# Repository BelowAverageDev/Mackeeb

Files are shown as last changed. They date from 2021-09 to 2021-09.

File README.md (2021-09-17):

# Mackeeb
2% macropad mechanical keyboard designed around macintosh keycaps  


## Usage
When you plug it in, the Mackeeb will run its main mode.

### Main mode
| Action | Result |
| --- | --- |
| Press Button 1 | Macro A |
| Press Button 2 | Macro B |
| Hold Button 1 | Macro C |
| Hold Button 2 | Macro D |
| Hold Button 1 & 2 together  | Switch to backlight set mode  |  

### Backlight set mode
| Action | Result |
| --- | --- |
| Press Button 1 | Increase Brightness |
| Press Button 2 | Decrease Brightness |
| Hold Button 1 & 2 together  | Switch to main mode |

### Changing macros
To set Macro A-D, you need to put the device in config mode using the following steps:
1. Unplug the Mackeeb
2. Hold down Button 1 & 2 together
3. Plug in the Mackeeb
4. The underglow will begin flashing slowly. You may release Button 1 & 2
5. A new drive titled `CIRCUITPY` should appear on your computer
6. Open `CIRCUITPY/main.py` in any text editor
7. Modify `BUTTON_A_KEYS`, `BUTTON_B_KEYS`, `BUTTON_C_KEYS`, `BUTTON_D_KEYS` to your liking
8. Save `main.py`
9. Unplug and re-plug the Mackeeb

Note: These macros can be sequences of keystrokes, modifier keys, and combinations. For example, you can do a complex action like: `[[Keycode.COMMAND, Keycode.F], "search", Keycode.ENTER]` to search for a string, and then hit enter!

If your macros do not work as expected, you likely made an error. You can debug your macros by connecting to the trinket over a serial port, where any errors will be printed.

## Building your own

### Materials
- [Trinket m0](https://www.adafruit.com/product/3500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)
- [Macintosh keycaps](https://www.keebmonkey.com/products/keebmonkey-mac-modular-artisan-keycap?_pos=1&_sid=b556e45d8&_ss=r)
- 2x Mechanical keyswitches
- 3d printer (or access to one)
- 1x 3mm LED
- 1x Resistor (I used 200 ohm)
- Wire (recommend silicon coated for flexibility)
- Soldering iron
- Solder
- Flux
- MicroUSB cable

### Circuit
Circuit Diagram

Note that the switch connected on pin 3 will be the switch in the back, and the switch connected on pin 4 will be the switch in the front. Additionally, the LED should be put through the keyswitch before soldering.

### Assembly

#### Trinket setup
1. Install CircuitPy 7  
First, you want to load CircuitPy 7 onto the trinket. Be sure to download **CircuitPy 7**!  
[Upgrade Circuitpy](https://learn.adafruit.com/adafruit-trinket-m0-circuitpython-arduino/circuitpython)  

2. Install CircuitPy 7 Libraries  
Download the CircuitPy libraries required for this build, but **make sure you download the v7 library bundle**:
[Download](https://learn.adafruit.com/welcome-to-circuitpython/circuitpython-libraries)
From this bundle we need:
    ```
    adafruit_hid
    adafruit_dotstar.mpy
    adafruit_pypixelbuf.mpy
    ```
Move these to `CIRCUITPY/lib`

3. Install Project Code  
Load the project code onto the trinket by moving `boot.py` and `main.py` to the `CIRCUITPY` drive that shows up when you plug in the trinket.

#### Soldering
Start by soldering all the wires you need to the trinket, making sure that the joints are flush with the bottom of the trinket.  
Next, place the trinket in the case with the wires sticking through the correct holes in the case.  
Then, solder the switches and led accoring to the diagram above.

TIP: Fitting the resistor can be a little tricky, so I soldered it between the LED ground lead and the rear switch ground lead in order to save space and prevent shorts.

Finally, test that the trinket is working with the switches

## Code
[About the code](code/README.md)

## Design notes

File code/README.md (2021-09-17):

# Code

### main.py
Contains the code controlling the keyswitch polling and handlers for keyswitch presses/depresses. Fully capitalized variable names are considered configuration variables and can be modified in config mode to your liking.

The following variables define user-modifyable configurations:  
| Variable | Importance |
| --- | --- |
| BUTTON_A_KEYS | Macro executed on Button 1 press |
| BUTTON_B_KEYS | Macro executed on Button 2 press |
| BUTTON_C_KEYS | Macro executed on Button 1 hold |
| BUTTON_D_KEYS | Macro executed on Button 2 hold |
| UNDERGLOW_BRIGHTNESS | Brightness of case lighting |
| UNDERGLOW_COLOR | Color of case lighting (rgb code or function) |
| DELAY | Polling rate of device |
| MODE_CHANGE_HOLD_DELAY | Time for both buttons hold before mode change |
| HOLD_DELAY | Time for single button hold to execute Macro C or D |

This code can only be modified in config mode which you can enter by holding down both switches while the device is booting.

For example, setting `UNDERGLOW_BRIGHTNESS` to `1.0` will make the underglow very bright.

Note: You may notice this code is incredibly messy; this is out of necessity. The trinket only as 32kb of available memory and after all necessary libraries are imported, we are left with around 10kb. This would be fine for our uses, however this 10kb is very fragmented. Because CircuitPython offers no way to defragment the heap, we are stuck in this state.

[Learn more about CircuitPython](https://circuitpython.org/)

### boot.py
Defines custom boot behavior for CircuitPython which is required for access to the `storage` module. This project uses `storage` to allow CircuitPython to write data to a file (`led_val`) so that backlight level can be saved.

Additionally, this file disables the `CIRCUITPY` drive from showing up unless it is booting into comfig mode.

It is not recommended to modify this code because if something goes wrong, your trinket may not boot. You would then need to completely reset the trinket.

[Learn more about why we need `boot.py` and the `storage` module](https://learn.adafruit.com/circuitpython-essentials/circuitpython-storage)

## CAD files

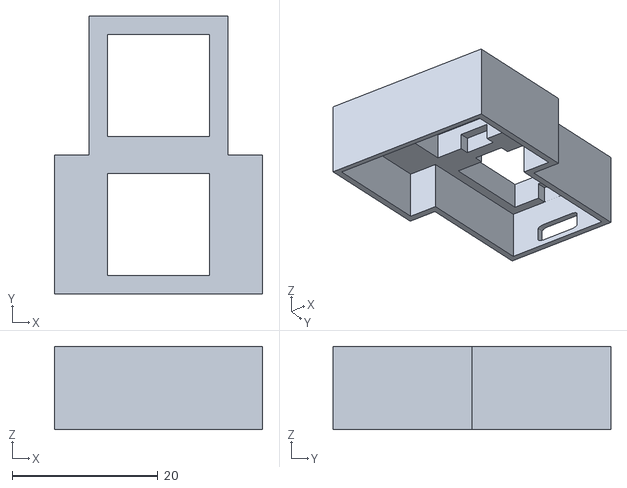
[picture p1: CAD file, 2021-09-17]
case/mackeeb_case_upper.stl
28.6 x 38.1 x 11.4

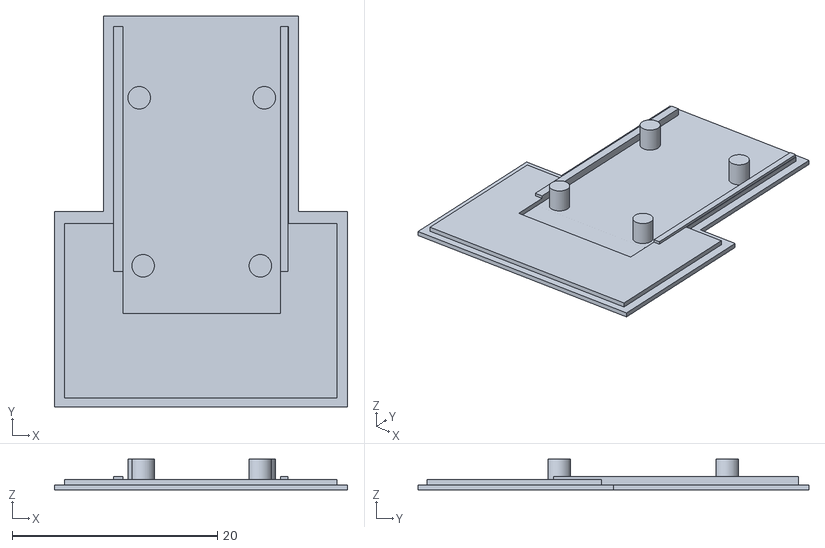
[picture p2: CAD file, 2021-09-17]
case/mackeeb_case_lower.stl
28.6 x 38.1 x 3.00

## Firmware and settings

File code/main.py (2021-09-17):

import gc
from adafruit_hid.keyboard import Keyboard, Keycode
def main_loop(led_mode):
    a_ign_release = False
    b_ign_release = False
    a_hold_revs = 0
    b_hold_revs = 0

    switch_a_pressed = False
    switch_b_pressed = False

    # if static color, just set here
    if not callable(UNDERGLOW_COLOR):
        dot[0] = UNDERGLOW_COLOR

    # regular mode, switch to led set mode if possible
    set_led_mode = False

    i = 0
    while True:
        if callable(UNDERGLOW_COLOR):
            # set dot to non-static color
            dot[0] = UNDERGLOW_COLOR(i & 255)

        switch_a_pressed = not switch_a.value
        switch_b_pressed = not switch_b.value

        if switch_a_pressed:
            a_hold_revs += 1
            if a_hold_revs == HOLD_DELAY_REVS and not switch_b_pressed and not set_led_mode:
                print("C pressed")
                send_keys(BUTTON_C_KEYS)
                gc.collect()
                a_ign_release = True
        elif a_hold_revs:
            if a_ign_release:
                # ignore this press (recover from changing mode)
                a_ign_release = False
            else:
                if set_led_mode:
                    # change led by 1
                    if led_mode < len(LED_MODES) - 1:
                        led_mode += 1
                    print("LED_MODE:", led_mode)
                    led.value = LED_MODES[led_mode]
                else:
                    # button released, send keystroke
                    if a_hold_revs < HOLD_DELAY_REVS:
                        print("A pressed")
                        send_keys(BUTTON_A_KEYS)
                        gc.collect()
            a_hold_revs = 0

        if switch_b_pressed:
            b_hold_revs += 1
            if b_hold_revs == HOLD_DELAY_REVS  and not switch_a_pressed and not set_led_mode:
                print("D pressed")
                send_keys(BUTTON_D_KEYS)
                gc.collect()
                b_ign_release = True
        elif b_hold_revs:
            if b_ign_release:
                # ignore this press (recover from changing mode)
                b_ign_release = False
            else:
                if set_led_mode:
                    # change led by 1
                    if led_mode != 0:
                        led_mode -= 1
                    print("LED_MODE:", led_mode)
                    led.value = LED_MODES[led_mode]
                else:
                    # button released, send keystroke
                    if b_hold_revs < HOLD_DELAY_REVS:
                        print("B pressed")
                        send_keys(BUTTON_B_KEYS)
                        gc.collect()
            b_hold_revs = 0

        # check if we need to switch to light set mode
        if (switch_a_pressed and switch_b_pressed) and (
            min(a_hold_revs, b_hold_revs) == MODE_CHANGE_HOLD_DELAY_REVS
        ):
            print("LED_SET_MODE:", not set_led_mode)
            blink_val = max(LED_MODES[led_mode], LED_MODES[1])
            for _ in range(3):
                led.value = LED_MODES[0]
                sleep(0.1)
                led.value = blink_val
                sleep(0.1)
            
            led.value = LED_MODES[led_mode]

            if set_led_mode:
                # save value if in led_mode
                with open(LED_FILE, "w") as f:
                    f.write(str(led_mode))
                    f.flush()

            # swap between led and keyboard mode
            set_led_mode = not set_led_mode
            # ignore next keyup
            a_ign_release = b_ign_release = True


        i = (i + 1) % 256  # run from 0 to 255
        sleep(DELAY)

gc.collect()
print(gc.mem_free())

import adafruit_dotstar as dotstar
print(gc.mem_free())
import board
import usb_hid
from digitalio import DigitalInOut, Direction, Pull
from analogio import AnalogOut
from adafruit_hid.keyboard_layout_us import KeyboardLayoutUS
from time import sleep

gc.collect()
print(gc.mem_free())

# NOTE: Try not to go crazy here, the memory is very fragmeneted
# and large strings may not work here
BUTTON_A_KEYS = ["Hello world!", Keycode.ENTER]
BUTTON_C_KEYS = [[Keycode.COMMAND, Keycode.F], "search", Keycode.ENTER]
BUTTON_B_KEYS = ["Hello I am a mackeeb! :) Please view my documentation to configure me!"]
BUTTON_D_KEYS = [[Keycode.ALT, Keycode.SHIFT, Keycode.H]]

# underglow brightness (0.0-1.0)
UNDERGLOW_BRIGHTNESS = 0.0

WHITE = (255, 255, 255)
BLACK = (0, 0, 0)
# underglow color (0,0,0)-(255,255,255)
# can be static or function depending on i
# 0 <= i <= 255
UNDERGLOW_COLOR = WHITE
# def UNDERGLOW_COLOR(i):
#     if i < 0:
#         return (0, 0, 0)
#     if i > 255:
#         return (0, 0, 0)
#     if i < 85:
#         return (int(i * 3), int(255 - (i * 3)), 0)
#     elif i < 170:
#         i -= 85
#         return (int(255 - i * 3), 0, int(i * 3))
#     else:
#         i -= 170
#         return (0, int(i * 3), int(255 - i * 3))

LED_FILE = "/led_val"
LED_MIN, LED_MAX = 65535 // 4 * 3, 65535
# set led modes list (modes 0-4) to a out values
LED_MODES = [i for i in range(LED_MIN, LED_MAX, (LED_MAX - LED_MIN) // 5)]
# set last mode to full voltage
LED_MODES[-1] = LED_MAX
# set first mode to 0 voltage
LED_MODES[0] = 0

# polling rates
DELAY = 0.001
MODE_CHANGE_HOLD_DELAY = 3
HOLD_DELAY = 1
MODE_CHANGE_HOLD_DELAY_REVS = round(MODE_CHANGE_HOLD_DELAY / DELAY / 10)
HOLD_DELAY_REVS = round(HOLD_DELAY / DELAY / 10)

# init kbd
kbd = Keyboard(usb_hid.devices)
kbd_layout = KeyboardLayoutUS(kbd)

# init dotstar (underglow RGB led)
dot = dotstar.DotStar(
    board.APA102_SCK, board.APA102_MOSI, 1, brightness=UNDERGLOW_BRIGHTNESS
)

# init led (backlight)
led = AnalogOut(board.D1)

# init switch_a
switch_a = DigitalInOut(board.D3)
switch_a.direction = Direction.INPUT
switch_a.pull = Pull.UP

# init switch_b
switch_b = DigitalInOut(board.D4)
switch_b.direction = Direction.INPUT
switch_b.pull = Pull.UP

led_mode = 0
try:
    with open(LED_FILE, "r") as f:
        led_mode = int(f.read()) % len(LED_MODES)
except Exception:
    pass

def send_keys(keys_list):
    for key in keys_list:
        if isinstance(key, str):
            kbd_layout.write(key)
        elif type(key) == list:
            kbd.send(*key)
        else:
            kbd.send(key)

led.value = LED_MODES[led_mode]


config_mode = 0
try:
    open(LED_FILE, "r+").close()

except OSError as e:
    config_mode = 1

print("config_mode:", config_mode)

if config_mode:
    # config mode
    dot.brightness = 0.5

    # blink white light
    while True:
        dot[0] = WHITE
        sleep(0.5)
        dot[0] = BLACK
        sleep(0.5)
else:
    main_loop(led_mode)

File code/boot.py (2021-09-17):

"""
boot.py

Executed when device boots

NOTE: Hold both switches to enter config mode
where you can view/edit this code!
"""

import board
from digitalio import DigitalInOut, Direction, Pull
import storage
import usb_cdc

# init switch_a
switch_a = DigitalInOut(board.D4)
switch_a.direction = Direction.INPUT
switch_a.pull = Pull.UP

# init switch_b
switch_b = DigitalInOut(board.D3)
switch_b.direction = Direction.INPUT
switch_b.pull = Pull.UP

# config mode if both switches are pressed on boot
config_mode = (not switch_a.value) and (not switch_b.value)

print("config_mode", config_mode)

# set writable in config mode
storage.remount("/", config_mode)

# If both switches are pressed
if config_mode:
    # config mode

    # enable usb drive
    storage.enable_usb_drive()
    # enable uart
    usb_cdc.enable()
else:
    # usage mode

    # disable usb drive
    storage.disable_usb_drive()
    # disable uart
    # usb_cdc.disable()

del config_mode
